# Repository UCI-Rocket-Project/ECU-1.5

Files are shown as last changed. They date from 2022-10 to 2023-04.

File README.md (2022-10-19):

# UCIRP Engine Control Unit (ECU)
Hardware design files for ECU v1.5 "Orion"

Minimal, stable ECU for VTF and launch.

## Used Packages
* Teensy 4.1 [symbol](https://github.com/XenGi/teensy_library) and [footprint](https://github.com/XenGi/teensy.pretty). Related files and license is located under `/teensylib`.

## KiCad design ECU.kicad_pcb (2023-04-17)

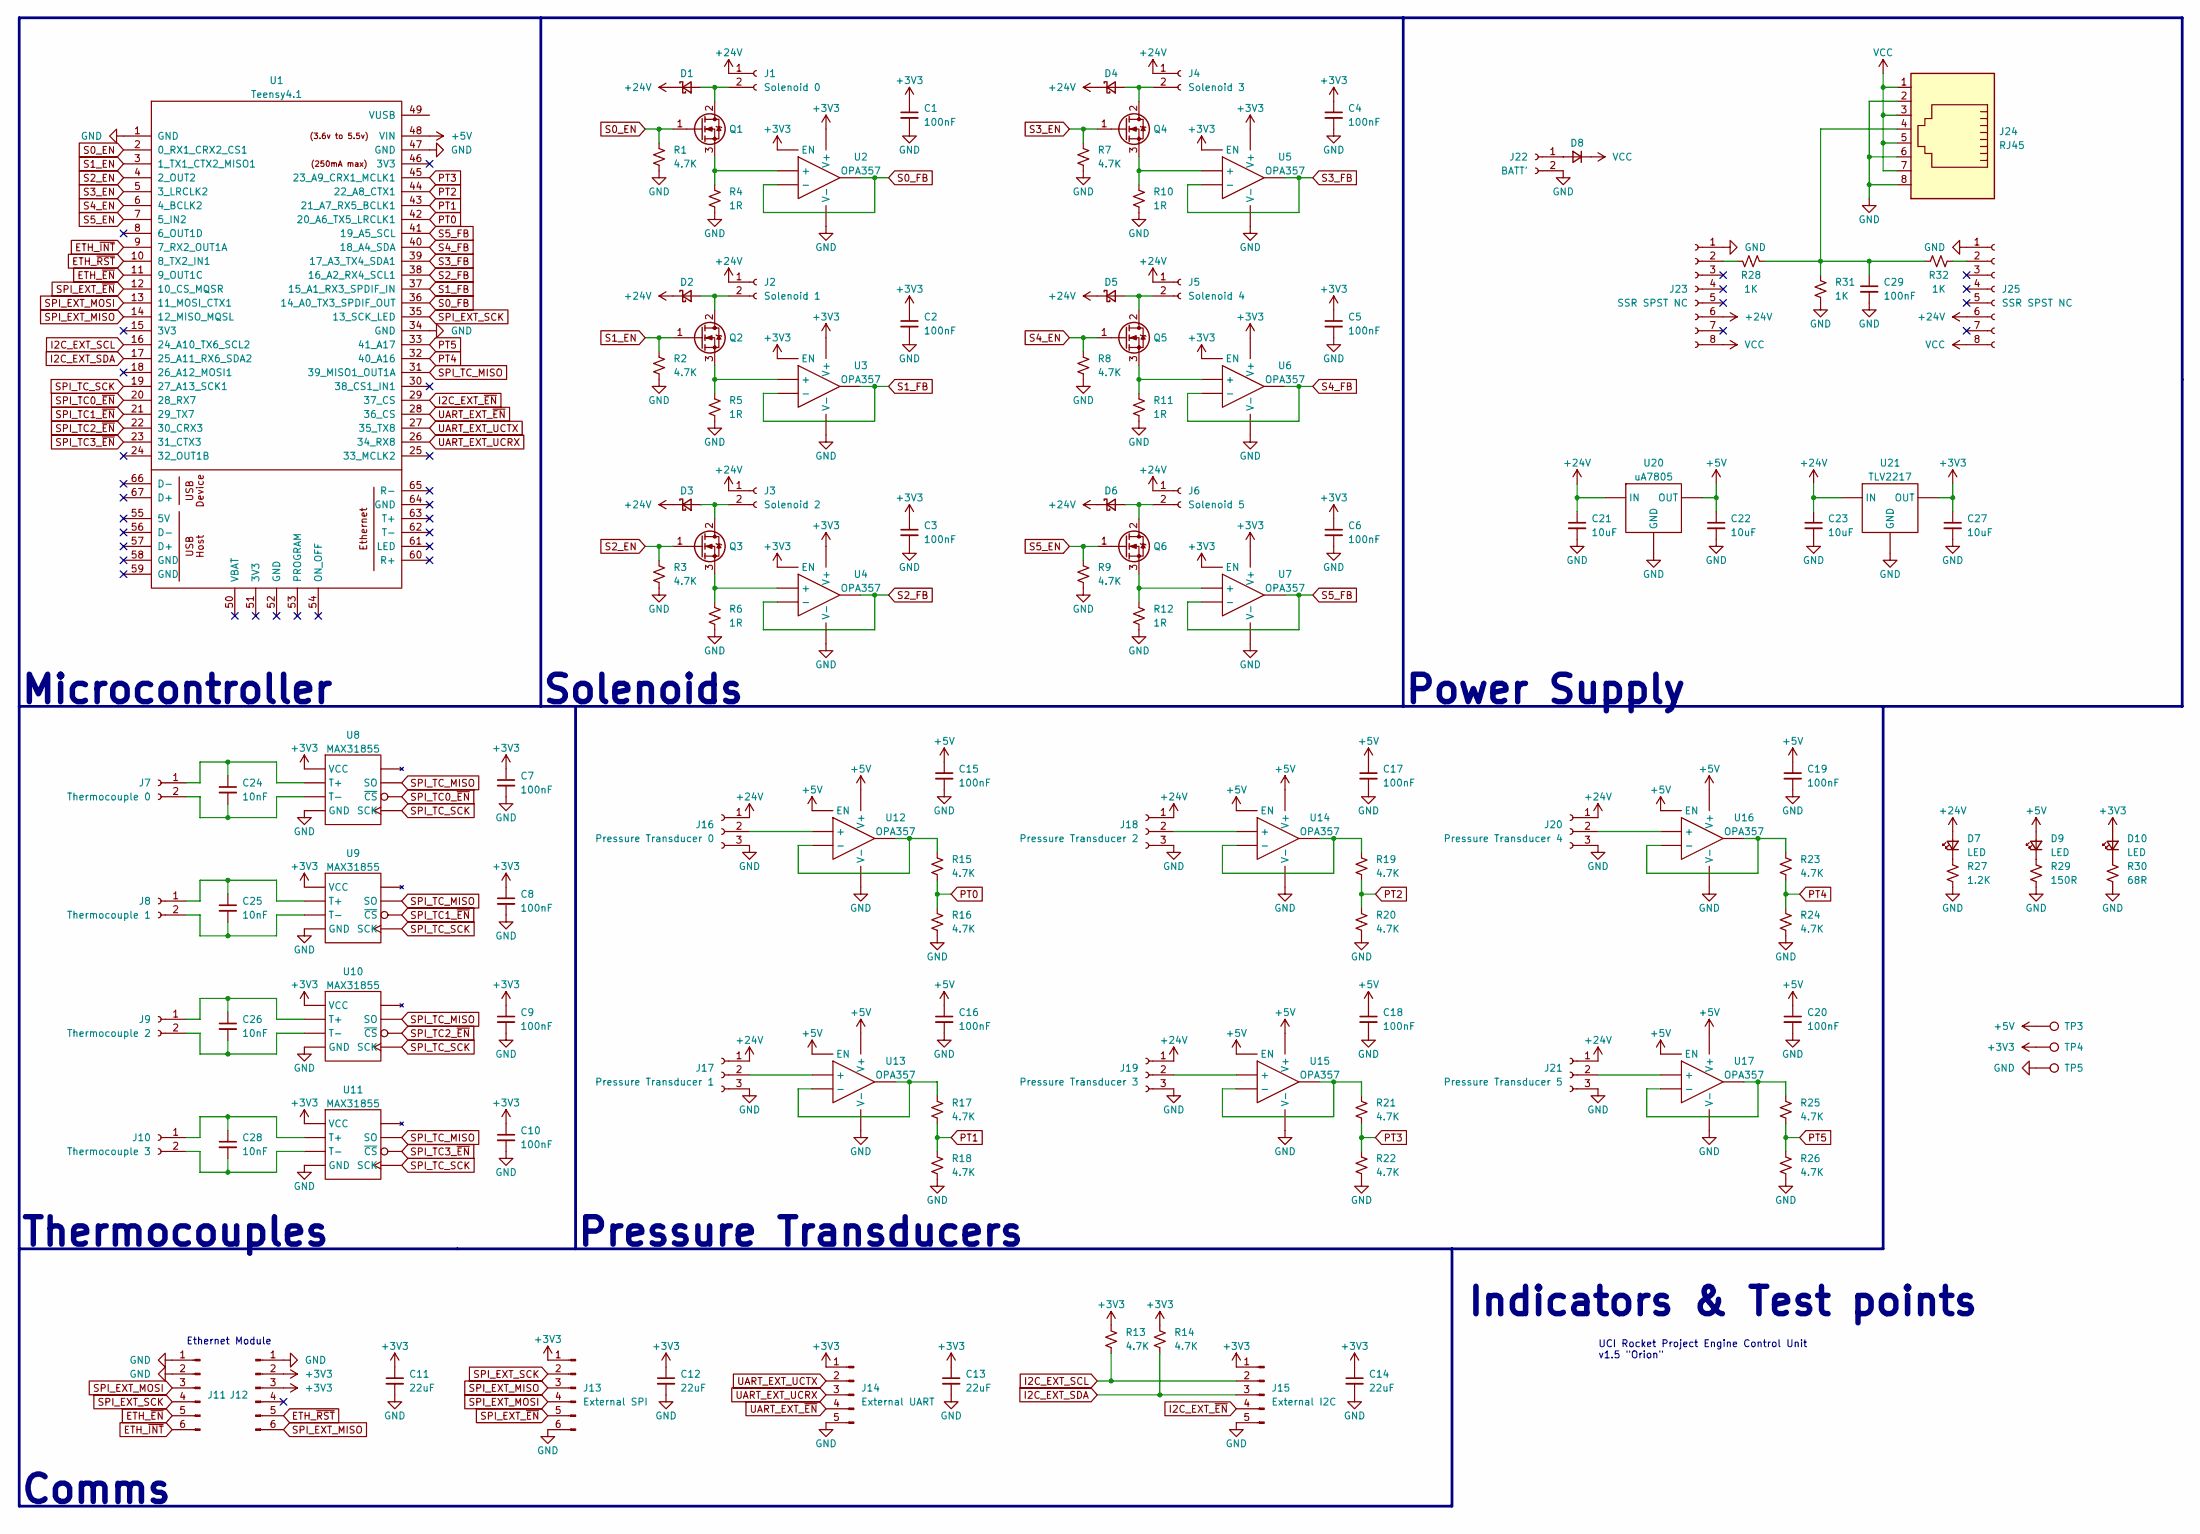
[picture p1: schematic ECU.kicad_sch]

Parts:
C1, C2, C3, C4, C5, C6, C7, C8, C9, C10, C15, C16, C17, C18, C19, C20, C29: 100nF; C_0603_1608Metric; Part # Generic 100nF 0603 MLCC
C11, C12, C13, C14: 22uF; C_0805_2012Metric; Part # Generic 22uF 0805 MLCC
C21, C22, C23, C27: 10uF; C_1206_3216Metric; Part # Generic 10uF 1206 MLCC
C24, C25, C26, C28: 10nF; C_0603_1608Metric; Part # Generic 10nF 0603 MLCC
D1, D2, D3, D4, D5, D6: D_SOD-523; Part # SDM20U40Q-7
D7, D9, D10: LED; D_0603_1608Metric; Part # Generic Red 0603 LED
D8: D_SMA
J1: Solenoid 0; TerminalBlock_bornier-2_P5.08mm; Part # Generic 2x5.08 Screw Terminal
J2: Solenoid 1; TerminalBlock_bornier-2_P5.08mm; Part # Generic 2x5.08 Screw Terminal
J3: Solenoid 2; TerminalBlock_bornier-2_P5.08mm; Part # Generic 2x5.08 Screw Terminal
J4: Solenoid 3; TerminalBlock_bornier-2_P5.08mm; Part # Generic 2x5.08 Screw Terminal
J5: Solenoid 4; TerminalBlock_bornier-2_P5.08mm; Part # Generic 2x5.08 Screw Terminal
J6: Solenoid 5; TerminalBlock_bornier-2_P5.08mm; Part # Generic 2x5.08 Screw Terminal
J7: Thermocouple 0; TerminalBlock_bornier-2_P5.08mm; Part # Generic 2x5.08 Screw Terminal
J8: Thermocouple 1; TerminalBlock_bornier-2_P5.08mm; Part # Generic 2x5.08 Screw Terminal
J9: Thermocouple 2; TerminalBlock_bornier-2_P5.08mm; Part # Generic 2x5.08 Screw Terminal
J10: Thermocouple 3; TerminalBlock_bornier-2_P5.08mm; Part # Generic 2x5.08 Screw Terminal
J11, J12: PinHeader_1x06_P2.54mm_Vertical; Part # Generic 6x2.54 Pin Header
J13: External SPI; PinHeader_1x06_P2.54mm_Vertical; Part # Generic 6x2.54 Pin Header
J14: External UART; PinHeader_1x05_P2.54mm_Vertical; Part # Generic 5x2.54 Pin Header
J15: External I2C; PinHeader_1x05_P2.54mm_Vertical; Part # Generic 5x2.54 Pin Header
J16: Pressure Transducer 0; TerminalBlock_bornier-3_P5.08mm; Part # Generic 3x5.08 Screw Terminal
J17: Pressure Transducer 1; TerminalBlock_bornier-3_P5.08mm; Part # Generic 3x5.08 Screw Terminal
J18: Pressure Transducer 2; TerminalBlock_bornier-3_P5.08mm; Part # Generic 3x5.08 Screw Terminal
J19: Pressure Transducer 3; TerminalBlock_bornier-3_P5.08mm; Part # Generic 3x5.08 Screw Terminal
J20: Pressure Transducer 4; TerminalBlock_bornier-3_P5.08mm; Part # Generic 3x5.08 Screw Terminal
J21: Pressure Transducer 5; TerminalBlock_bornier-3_P5.08mm; Part # Generic 3x5.08 Screw Terminal
J22: BATT'; TerminalBlock_bornier-2_P5.08mm; Part # Generic 2x5.08 Screw Terminal
J23, J25: SSR SPST NC; SIP-8_19x3mm_P2.54mm
J24: RJ45; RJ45_Amphenol_54602-x08_Horizontal
Q1, Q2, Q3, Q4, Q5, Q6: TO-220-3_Vertical; Part # CSD18542KCS
R1, R2, R3, R7, R8, R9, R13, R14, R15, R16, R17, R18, R19, R20, R21, R22, R23, R24, R25, R26: 4.7K; R_0603_1608Metric; Part # Generic 4.7K 0603 Resistor
R4, R5, R6, R10, R11, R12: 1R; R_0603_1608Metric; Part # Generic 1R 1W 0603 Resistor
R27: 1.2K; R_0603_1608Metric; Part # Generic 1.2K 0603 Resistor
R28, R31, R32: 1K; R_2512_6332Metric
R29: 150R; R_0603_1608Metric; Part # Generic 150R 0603 Resistor
R30: 68R; R_0603_1608Metric; Part # Generic 68R 0603 Resistor
TP3, TP4, TP5: TestPoint_Pad_D4.0mm
U1: Teensy4.1; Teensy41
U2, U3, U4, U5, U6, U7, U12, U13, U14, U15, U16, U17: OPA357; SOT-23-6; Part # OPA357AIDBVT
U8, U9, U10, U11: MAX31855; SOIC-8_3.9x4.9mm_P1.27mm; Part # MAX31855KASA+T
U20: uA7805; TO-220-3_Vertical; Part # UA7805CKCT
U21: TLV2217; TO-220-3_Vertical; Part # TLV2217-33KCSE3

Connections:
+3V3: C1.1, C2.1, C3.1, C4.1, C5.1, C6.1, C7.1, C8.1, C9.1, C10.1, C11.1, C12.1, C13.1, C14.1, C27.1, D10.2 (A), J12.2, J12.3, J13.1, J14.1, J15.1, R13.1, R14.1, TP4.1, U2.5 (EN), U2.6 (V+), U3.5 (EN), U3.6 (V+), U4.5 (EN), U4.6 (V+), U5.5 (EN), U5.6 (V+), U6.5 (EN), U6.6 (V+), U7.5 (EN), U7.6 (V+), U8.4 (VCC), U9.4 (VCC), U10.4 (VCC), U11.4 (VCC), U21.3 (OUT)
+5V: C15.1, C16.1, C17.1, C18.1, C19.1, C20.1, C22.1, D9.2 (A), TP3.1, U1.48 (VIN), U12.5 (EN), U12.6 (V+), U13.5 (EN), U13.6 (V+), U14.5 (EN), U14.6 (V+), U15.5 (EN), U15.6 (V+), U16.5 (EN), U16.6 (V+), U17.5 (EN), U17.6 (V+), U20.3 (OUT)
+24V: C21.1, C23.1, D1.1 (K), D2.1 (K), D3.1 (K), D4.1 (K), D5.1 (K), D6.1 (K), D7.2 (A), J1.1, J2.1, J3.1, J4.1, J5.1, J6.1, J16.1, J17.1, J18.1, J19.1, J20.1, J21.1, J23.6, J25.6, U20.1 (IN), U21.1 (IN)
ETH_~EN: J11.5, U1.11 (9_OUT1C)
ETH_~INT: J11.6, U1.9 (7_RX2_OUT1A)
ETH_~RST: J12.5, U1.10 (8_TX2_IN1)
GND: C1.2, C2.2, C3.2, C4.2, C5.2, C6.2, C7.2, C8.2, C9.2, C10.2, C11.2, C12.2, C13.2, C14.2, C15.2, C16.2, C17.2, C18.2, C19.2, C20.2, C21.2, C22.2, C23.2, C27.2, C29.2, J11.1, J11.2, J12.1, J13.6, J14.5, J15.5, J16.3, J17.3, J18.3, J19.3, J20.3, J21.3, J22.2, J23.1, J24.2, J24.6, J24.8, J25.1, R1.2, R2.2, R3.2, R4.2, R5.2, R6.2, R7.2, R8.2, R9.2, R10.2, R11.2, R12.2, R16.2, R18.2, R20.2, R22.2, R24.2, R26.2, R27.2, R29.2, R30.2, R31.2, TP5.1, U1.1 (GND), U1.34 (GND), U1.47 (GND), U2.2 (V-), U3.2 (V-), U4.2 (V-), U5.2 (V-), U6.2 (V-), U7.2 (V-), U8.1 (GND), U9.1 (GND), U10.1 (GND), U11.1 (GND), U12.2 (V-), U13.2 (V-), U14.2 (V-), U15.2 (V-), U16.2 (V-), U17.2 (V-), U20.2 (GND), U21.2 (GND)
I2C_EXT_SCL: J15.2, R13.2, U1.16 (24_A10_TX6_SCL2)
I2C_EXT_SDA: J15.3, R14.2, U1.17 (25_A11_RX6_SDA2)
I2C_EXT_~EN: J15.4, U1.29 (37_CS)
unnamed: C24.1, J7.1, U8.3 (T+)
unnamed: C24.2, J7.2, U8.2 (T-)
unnamed: C25.1, J8.1, U9.3 (T+)
unnamed: C25.2, J8.2, U9.2 (T-)
unnamed: C26.1, J9.1, U10.3 (T+)
unnamed: C26.2, J9.2, U10.2 (T-)
unnamed: C28.1, J10.1, U11.3 (T+)
unnamed: C28.2, J10.2, U11.2 (T-)
unnamed: C29.1, J24.4, R28.1, R31.1, R32.1
unnamed: D1.2 (A), J1.2, Q1.2 (D)
unnamed: D2.2 (A), J2.2, Q2.2 (D)
unnamed: D3.2 (A), J3.2, Q3.2 (D)
unnamed: D4.2 (A), J4.2, Q4.2 (D)
unnamed: D5.2 (A), J5.2, Q5.2 (D)
unnamed: D6.2 (A), J6.2, Q6.2 (D)
unnamed: D7.1 (K), R27.1
unnamed: D9.1 (K), R29.1
unnamed: D10.1 (K), R30.1
unnamed: J16.2, U12.3 (+)
unnamed: J17.2, U13.3 (+)
unnamed: J18.2, U14.3 (+)
unnamed: J19.2, U15.3 (+)
unnamed: J20.2, U16.3 (+)
unnamed: J21.2, U17.3 (+)
unnamed: D8.2 (A), J22.1
unnamed: J23.2, R28.2
unnamed: J25.2, R32.2
unnamed: Q1.3 (S), R4.1, U2.3 (+)
unnamed: Q2.3 (S), R5.1, U3.3 (+)
unnamed: Q3.3 (S), R6.1, U4.3 (+)
unnamed: Q4.3 (S), R10.1, U5.3 (+)
unnamed: Q5.3 (S), R11.1, U6.3 (+)
unnamed: Q6.3 (S), R12.1, U7.3 (+)
unnamed: R15.1, U12.1, U12.4 (-)
unnamed: R17.1, U13.1, U13.4 (-)
unnamed: R19.1, U14.1, U14.4 (-)
unnamed: R21.1, U15.1, U15.4 (-)
unnamed: R23.1, U16.1, U16.4 (-)
unnamed: R25.1, U17.1, U17.4 (-)
PT0: R15.2, R16.1, U1.42 (20_A6_TX5_LRCLK1)
PT1: R17.2, R18.1, U1.43 (21_A7_RX5_BCLK1)
PT2: R19.2, R20.1, U1.44 (22_A8_CTX1)
PT3: R21.2, R22.1, U1.45 (23_A9_CRX1_MCLK1)
PT4: R23.2, R24.1, U1.32 (40_A16)
PT5: R25.2, R26.1, U1.33 (41_A17)
S0_EN: Q1.1 (G), R1.1, U1.2 (0_RX1_CRX2_CS1)
S0_FB: U1.36 (14_A0_TX3_SPDIF_OUT), U2.1, U2.4 (-)
S1_EN: Q2.1 (G), R2.1, U1.3 (1_TX1_CTX2_MISO1)
S1_FB: U1.37 (15_A1_RX3_SPDIF_IN), U3.1, U3.4 (-)
S2_EN: Q3.1 (G), R3.1, U1.4 (2_OUT2)
S2_FB: U1.38 (16_A2_RX4_SCL1), U4.1, U4.4 (-)
S3_EN: Q4.1 (G), R7.1, U1.5 (3_LRCLK2)
S3_FB: U1.39 (17_A3_TX4_SDA1), U5.1, U5.4 (-)
S4_EN: Q5.1 (G), R8.1, U1.6 (4_BCLK2)
S4_FB: U1.40 (18_A4_SDA), U6.1, U6.4 (-)
S5_EN: Q6.1 (G), R9.1, U1.7 (5_IN2)
S5_FB: U1.41 (19_A5_SCL), U7.1, U7.4 (-)
SPI_EXT_MISO: J12.6, J13.3, U1.14 (12_MISO_MQSL)
SPI_EXT_MOSI: J11.3, J13.4, U1.13 (11_MOSI_CTX1)
SPI_EXT_SCK: J11.4, J13.2, U1.35 (13_SCK_LED)
SPI_EXT_~EN: J13.5, U1.12 (10_CS_MQSR)
SPI_TC0_~EN: U1.20 (28_RX7), U8.6 (~CS)
SPI_TC1_~EN: U1.21 (29_TX7), U9.6 (~CS)
SPI_TC2_~EN: U1.22 (30_CRX3), U10.6 (~CS)
SPI_TC3_~EN: U1.23 (31_CTX3), U11.6 (~CS)
SPI_TC_MISO: U1.31 (39_MISO1_OUT1A), U8.7 (SO), U9.7 (SO), U10.7 (SO), U11.7 (SO)
SPI_TC_SCK: U1.19 (27_A13_SCK1), U8.5 (SCK), U9.5 (SCK), U10.5 (SCK), U11.5 (SCK)
UART_EXT_UCRX: J14.3, U1.26 (34_RX8)
UART_EXT_UCTX: J14.2, U1.27 (35_TX8)
UART_EXT_~EN: J14.4, U1.28 (36_CS)
VCC: D8.1 (K), J23.8, J24.1, J24.3, J24.5, J24.7, J25.8

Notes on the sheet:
Microcontroller
Pressure Transducers
Solenoids
Thermocouples
UCI Rocket Project Engine Control Unit v1.5 "Orion"
Ethernet Module
Indicators & Test points
Comms
Power Supply

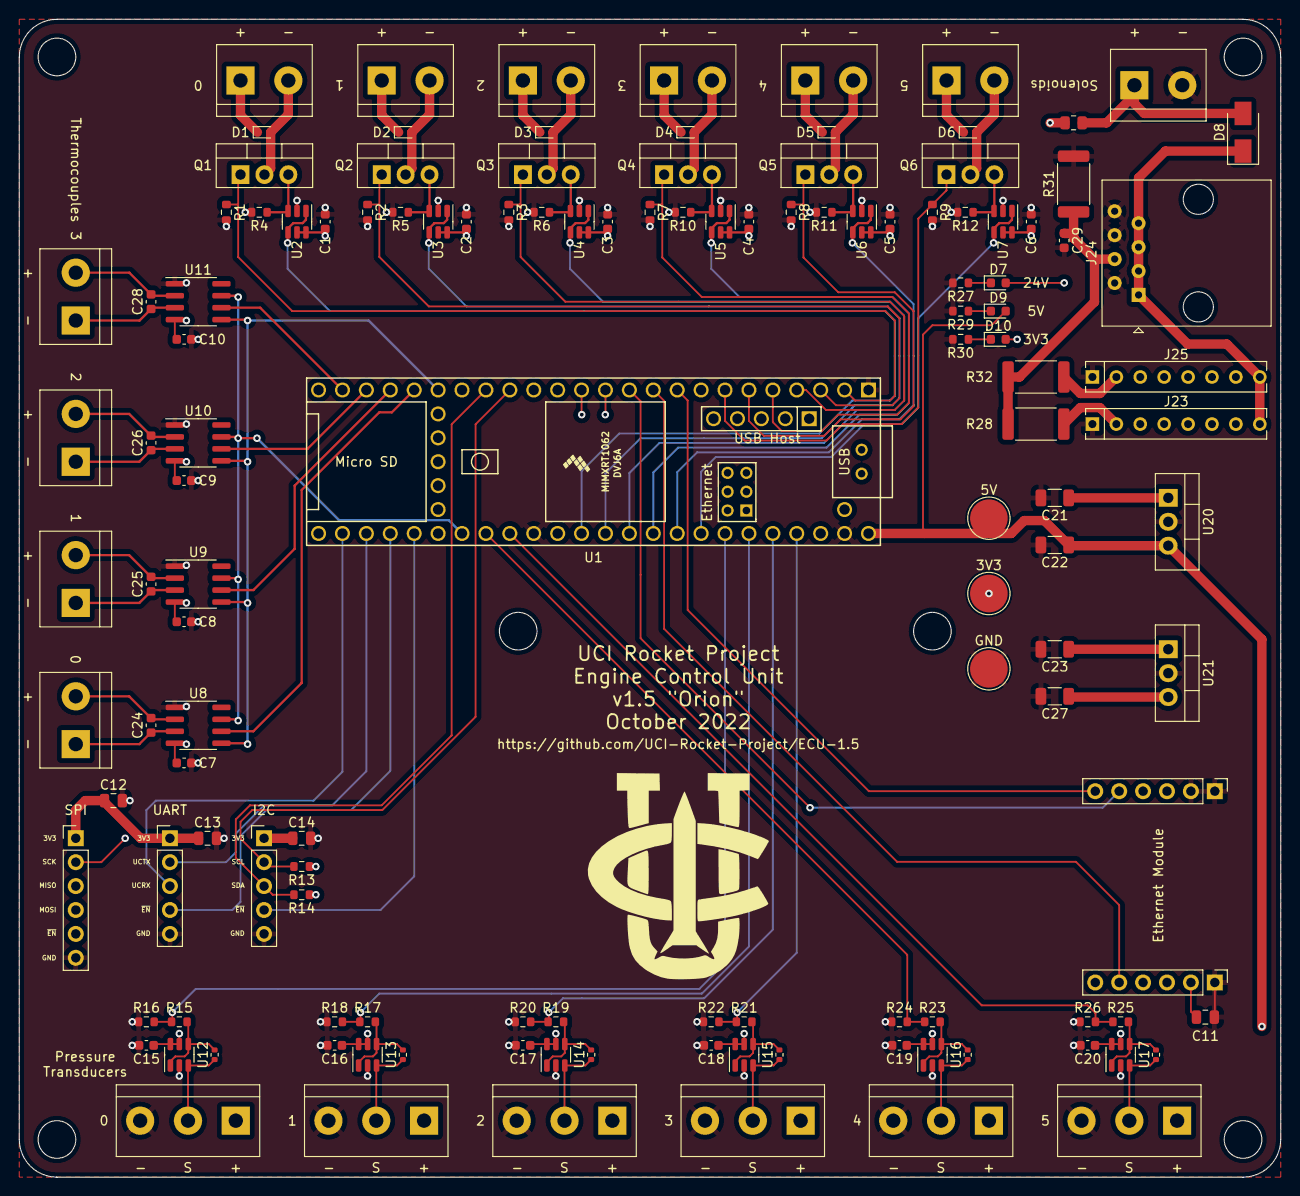
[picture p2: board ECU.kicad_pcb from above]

Board: 4 copper layers, 134.0 x 123.0 mm, 124 parts (0 on the bottom side), 81 nets.

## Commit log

2022-10-19 Add teensy symbol and footprint
2022-10-20 Add ucontroller & solenoid switching design
    [ECU.kicad_sch]
2022-10-20 Add thermocouple design
    [ECU.kicad_sch]
2022-10-21 Add ethernet & external serial comms ports
    [ECU.kicad_sch]
2022-10-21 Reuse ethernet SPI bus for external devices
    [ECU.kicad_sch]
2022-10-21 Add I2C bus pullups
    [ECU.kicad_sch]
2022-10-22 Add pressure transducer design
    [ECU.kicad_sch]
2022-10-22 Add power supply, indicators, & test points
    [ECU.kicad_sch]
2022-10-22 Add PCB layout
    [ECU.kicad_pcb, ECU.kicad_sch]
2022-10-22 Correct resistor part numbers
    [ECU.kicad_sch]
2022-10-23 Add logo to silkscreen
    [ECU.kicad_pcb]
2022-10-23 Add silkscreen labels for screw terminals
    [ECU.kicad_pcb]
2023-04-17 Redesign power supply
    [ECU.kicad_pcb, ECU.kicad_sch]
2023-04-17 Add filter caps to TC input
    [ECU.kicad_pcb, ECU.kicad_sch]
2023-04-17 Integrate power switching & cutoff system
    [ECU.kicad_pcb, ECU.kicad_sch]
2023-04-17 Add bypass path for PT frontend
    [ECU.kicad_pcb]
2023-04-17 Add bypass path for cutoff system
    [ECU.kicad_pcb]
